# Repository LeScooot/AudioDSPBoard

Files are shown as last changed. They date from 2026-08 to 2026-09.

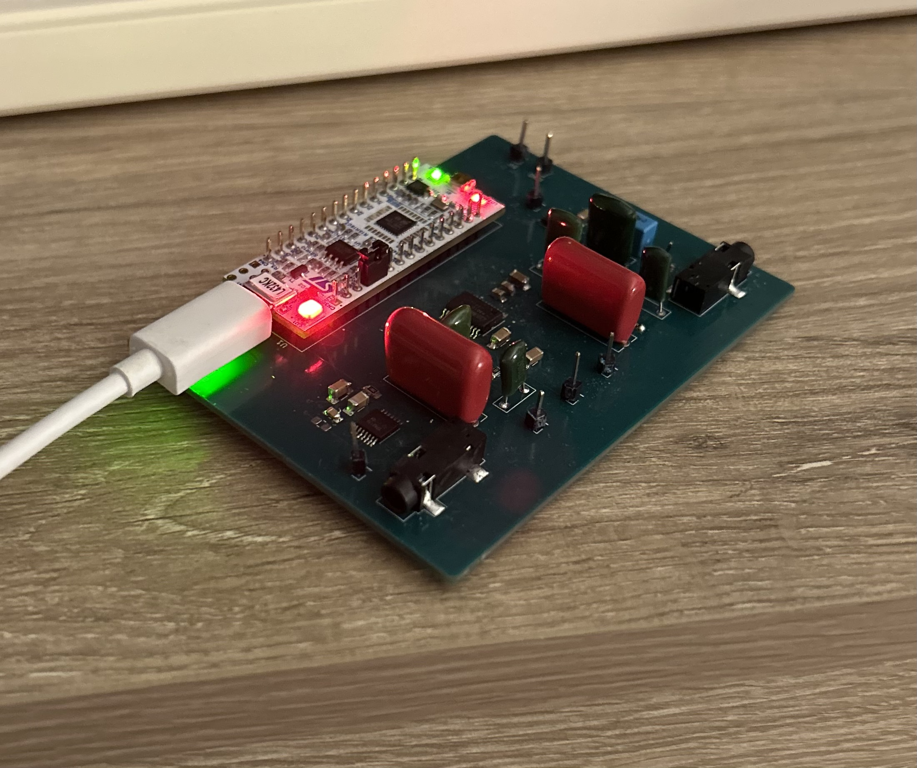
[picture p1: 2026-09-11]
hero.png

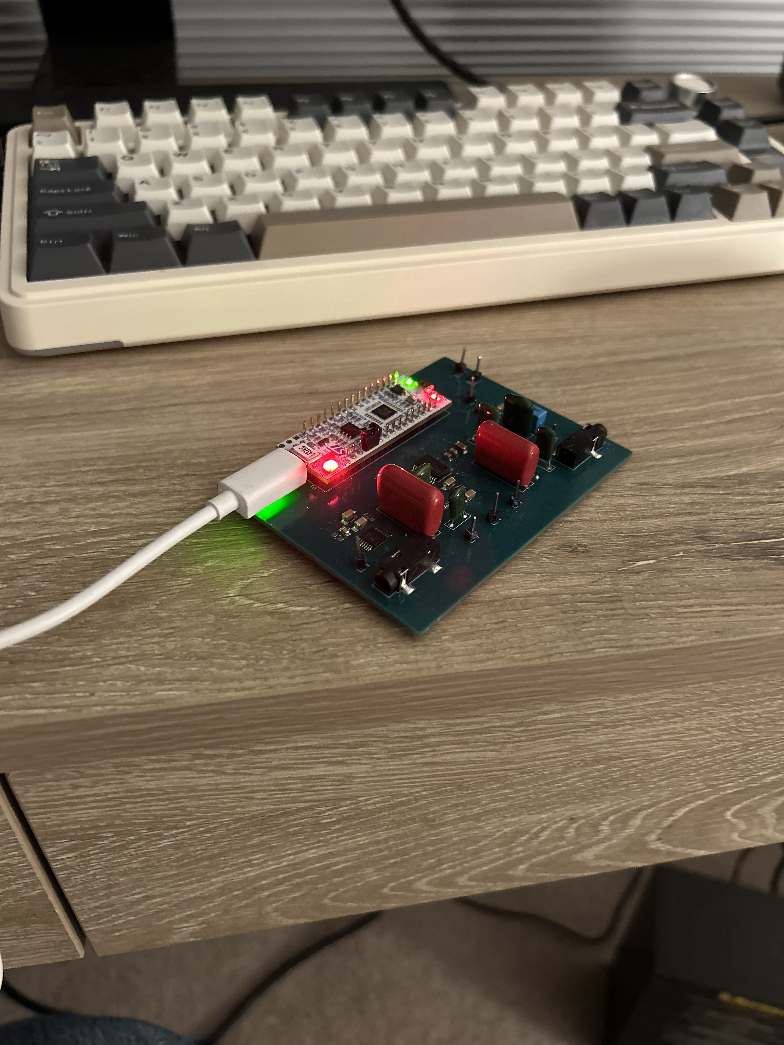
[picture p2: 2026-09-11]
audio_codec_v0/hero.png

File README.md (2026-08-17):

## Members
Ryan Jeronimus, EE Student (Graduating 2027)

ryanjeronimus@vt.edu

## Mentor
MENTOR NAME HERE

## Current Status
IN PROGRESS

## Project Overview

PCB featuring 3.5mm audio inputs and outputs, an audio CODEC for high-quality audio sampling and reconstruction, bare-metal STM32 board for implementing DSP algorithms, and a small i2c LED display for displaying information pertaining to the audio effects implemented on the STM32 (real-time display). Features programmable potentiometers and buttons for use in DSP implementations. Battery powered for ease of use when travelling. The system is intended as a portable, real-time audio effects processor for general listening applications.

## Educational Value Added
This project teaches about PCB design, power electronics, bare-metal C programming practices, and DSP for audio applications (which includes topics widely applicable to general DSP). Audio-specific communication protocols such as i2s would also be taught with the completion of this project.
## Tasks

<!-- Your Text Here. You may work with your mentor on this later when they are assigned -->

## Design Decisions

<!-- Your Text Here. You may work with your mentor on this later when they are assigned -->

## Design Misc

<!-- Your Text Here. You may work with your mentor on this later when they are assigned -->

## Steps for Documenting Your Design Process

<!-- Your Text Here. You may work with your mentor on this later when they are assigned -->

## BOM + Component Cost

<!-- Your Text Here. You may work with your mentor on this later when they are assigned -->

## Timeline

<!-- Your Text Here. You may work with your mentor on this later when they are assigned -->

## Useful Links

<!-- Your Text Here. You may work with your mentor on this later when they are assigned -->

## Log

<!-- Your Text Here. You may work with your mentor on this later when they are assigned -->

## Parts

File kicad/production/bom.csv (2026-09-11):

Designator | Footprint | Quantity | Value | LCSC Part #
C10, C14, C16, C6 | 1206 | 4 | 10uF | C13585
C11, C12, C20, C26 | 0805 | 4 | 100nF | C49678
C18, C19 | 1206 | 2 | 1uF | C1848
C23 | 1206 | 1 | 22uF | C12891
C4, C7 | 0805 | 2 | 10uF | C15850
D1 | 0805 | 1 | LED | C2297
R1 | 0805 | 1 | 130 | C178174
R10 | 0805 | 1 | 470k | C17709
R11 | 0805 | 1 | 10k | C17414
R14, R15, R16, R22 | 0805 | 4 | 1k | C702831
R17, R18 | 0805 | 2 | 2M2 | C17513
R20, R27 | 0805 | 2 | 22k | C702833
R21, R28 | 0805 | 2 | 6.8k | C17772
U13 | SOP65P640X120-14N | 1 | TPA6139A2PWR | C2870791
U2 | DB24 | 1 | PCM3010DB | C2873586
U3, U4, U5, U6 | SOT-23-5 | 4 | TLV9061xDBV | C398358

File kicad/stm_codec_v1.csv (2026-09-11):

Reference | Qty | Value | DNP | Exclude from BOM | Exclude from Board | LCSC Part # | Footprint | Datasheet
C1,C17 | 2 | 1uF | DNP | Excluded from BOM |  |  | Capacitor_THT:C_Rect_L16.5mm_W4.9mm_P15.00mm_MKT | ~
C4,C7 | 2 | 10uF |  |  |  | C1713 | Capacitor_SMD:C_0805_2012Metric_Pad1.18x1.45mm_HandSolder | ~
C6,C10,C14,C16 | 4 | 10uF |  |  |  | C1849 | Capacitor_SMD:C_1206_3216Metric_Pad1.33x1.80mm_HandSolder | ~
C11,C12,C20,C26 | 4 | 100nF |  |  |  | C1711 | Capacitor_SMD:C_0805_2012Metric_Pad1.18x1.45mm_HandSolder | ~
C18 | 1 | 1uF |  |  |  | C1848 | Capacitor_SMD:C_1206_3216Metric_Pad1.33x1.80mm_HandSolder | ~
C19 | 1 | 1uf |  |  |  | C1848 | Capacitor_SMD:C_1206_3216Metric_Pad1.33x1.80mm_HandSolder | ~
C21 | 1 | 150p | DNP | Excluded from BOM |  |  | Capacitor_THT:C_Rect_L7.0mm_W2.5mm_P5.00mm | ~
C22 | 1 | 100n | DNP | Excluded from BOM |  |  | Capacitor_THT:C_Rect_L9.0mm_W4.0mm_P7.50mm_MKT | ~
C23 | 1 | 22uF |  |  |  | C77088 | Capacitor_SMD:C_1206_3216Metric_Pad1.33x1.80mm_HandSolder | ~
C24 | 1 | 330p | DNP | Excluded from BOM |  |  | Capacitor_THT:C_Rect_L9.0mm_W4.0mm_P7.50mm_MKT | ~
C25,C36 | 2 | 1n | DNP | Excluded from BOM |  |  | Capacitor_THT:C_Rect_L7.0mm_W2.5mm_P5.00mm | ~
C37 | 1 | 330p | DNP | Excluded from BOM |  |  | Capacitor_THT:C_Rect_L7.0mm_W2.5mm_P5.00mm | ~
D1 | 1 | LED |  |  |  | C6795833 | LED_SMD:LED_0805_2012Metric_Pad1.15x1.40mm_HandSolder | ~
J1,J4,J5,J6,J7,J8,J9,J10 | 8 | Conn_01x01_Pin | DNP | Excluded from BOM |  |  | Connector_PinHeader_2.54mm:PinHeader_1x01_P2.54mm_Vertical | ~
J2,J3 | 2 | AudioJack3 | DNP | Excluded from BOM |  |  | Connector_Audio:Jack_3.5mm_CUI_SJ-3523-SMT_Horizontal | ~
R1 | 1 | 130 |  |  |  | C178174 | Resistor_SMD:R_0805_2012Metric_Pad1.20x1.40mm_HandSolder | ~
R10 | 1 | 470k |  |  |  | C49330265 | Resistor_SMD:R_0805_2012Metric_Pad1.20x1.40mm_HandSolder | ~
R11 | 1 | 10k |  |  |  | C702829 | Resistor_SMD:R_0805_2012Metric_Pad1.20x1.40mm_HandSolder | ~
R12 | 1 | 0 | DNP | Excluded from BOM |  |  | Resistor_SMD:R_0805_2012Metric_Pad1.20x1.40mm_HandSolder | ~
R14,R15,R16,R22 | 4 | 1k |  |  |  | C702831 | Resistor_SMD:R_0805_2012Metric_Pad1.20x1.40mm_HandSolder | ~
R17,R18 | 2 | 2M2 |  |  |  | C269574 | Resistor_SMD:R_0805_2012Metric_Pad1.20x1.40mm_HandSolder | ~
R20,R27 | 2 | 22k |  |  |  | C702833 | Resistor_SMD:R_0805_2012Metric_Pad1.20x1.40mm_HandSolder | ~
R21,R28 | 2 | 6.8k |  |  |  | C178216 | Resistor_SMD:R_0805_2012Metric_Pad1.20x1.40mm_HandSolder | ~
U1 | 1 | NUCLEO-L432KC | DNP | Excluded from BOM |  |  | ryan_footprints:MODULE_NUCLEO-L432KC
U2 | 1 | PCM3010DB |  |  |  | C2873586 | ryan_footprints:DB24 | https://www.ti.com/lit/gpn/pcm3010
U3,U4,U5,U6 | 4 | TLV9061xDBV |  |  |  | C398358 | Package_TO_SOT_SMD:SOT-23-5 | https://www.ti.com/lit/ds/symlink/tlv9061.pdf
U13 | 1 | TPA6139A2PWR |  |  |  | C2870791 | ryan_footprints:SOP65P640X120-14N

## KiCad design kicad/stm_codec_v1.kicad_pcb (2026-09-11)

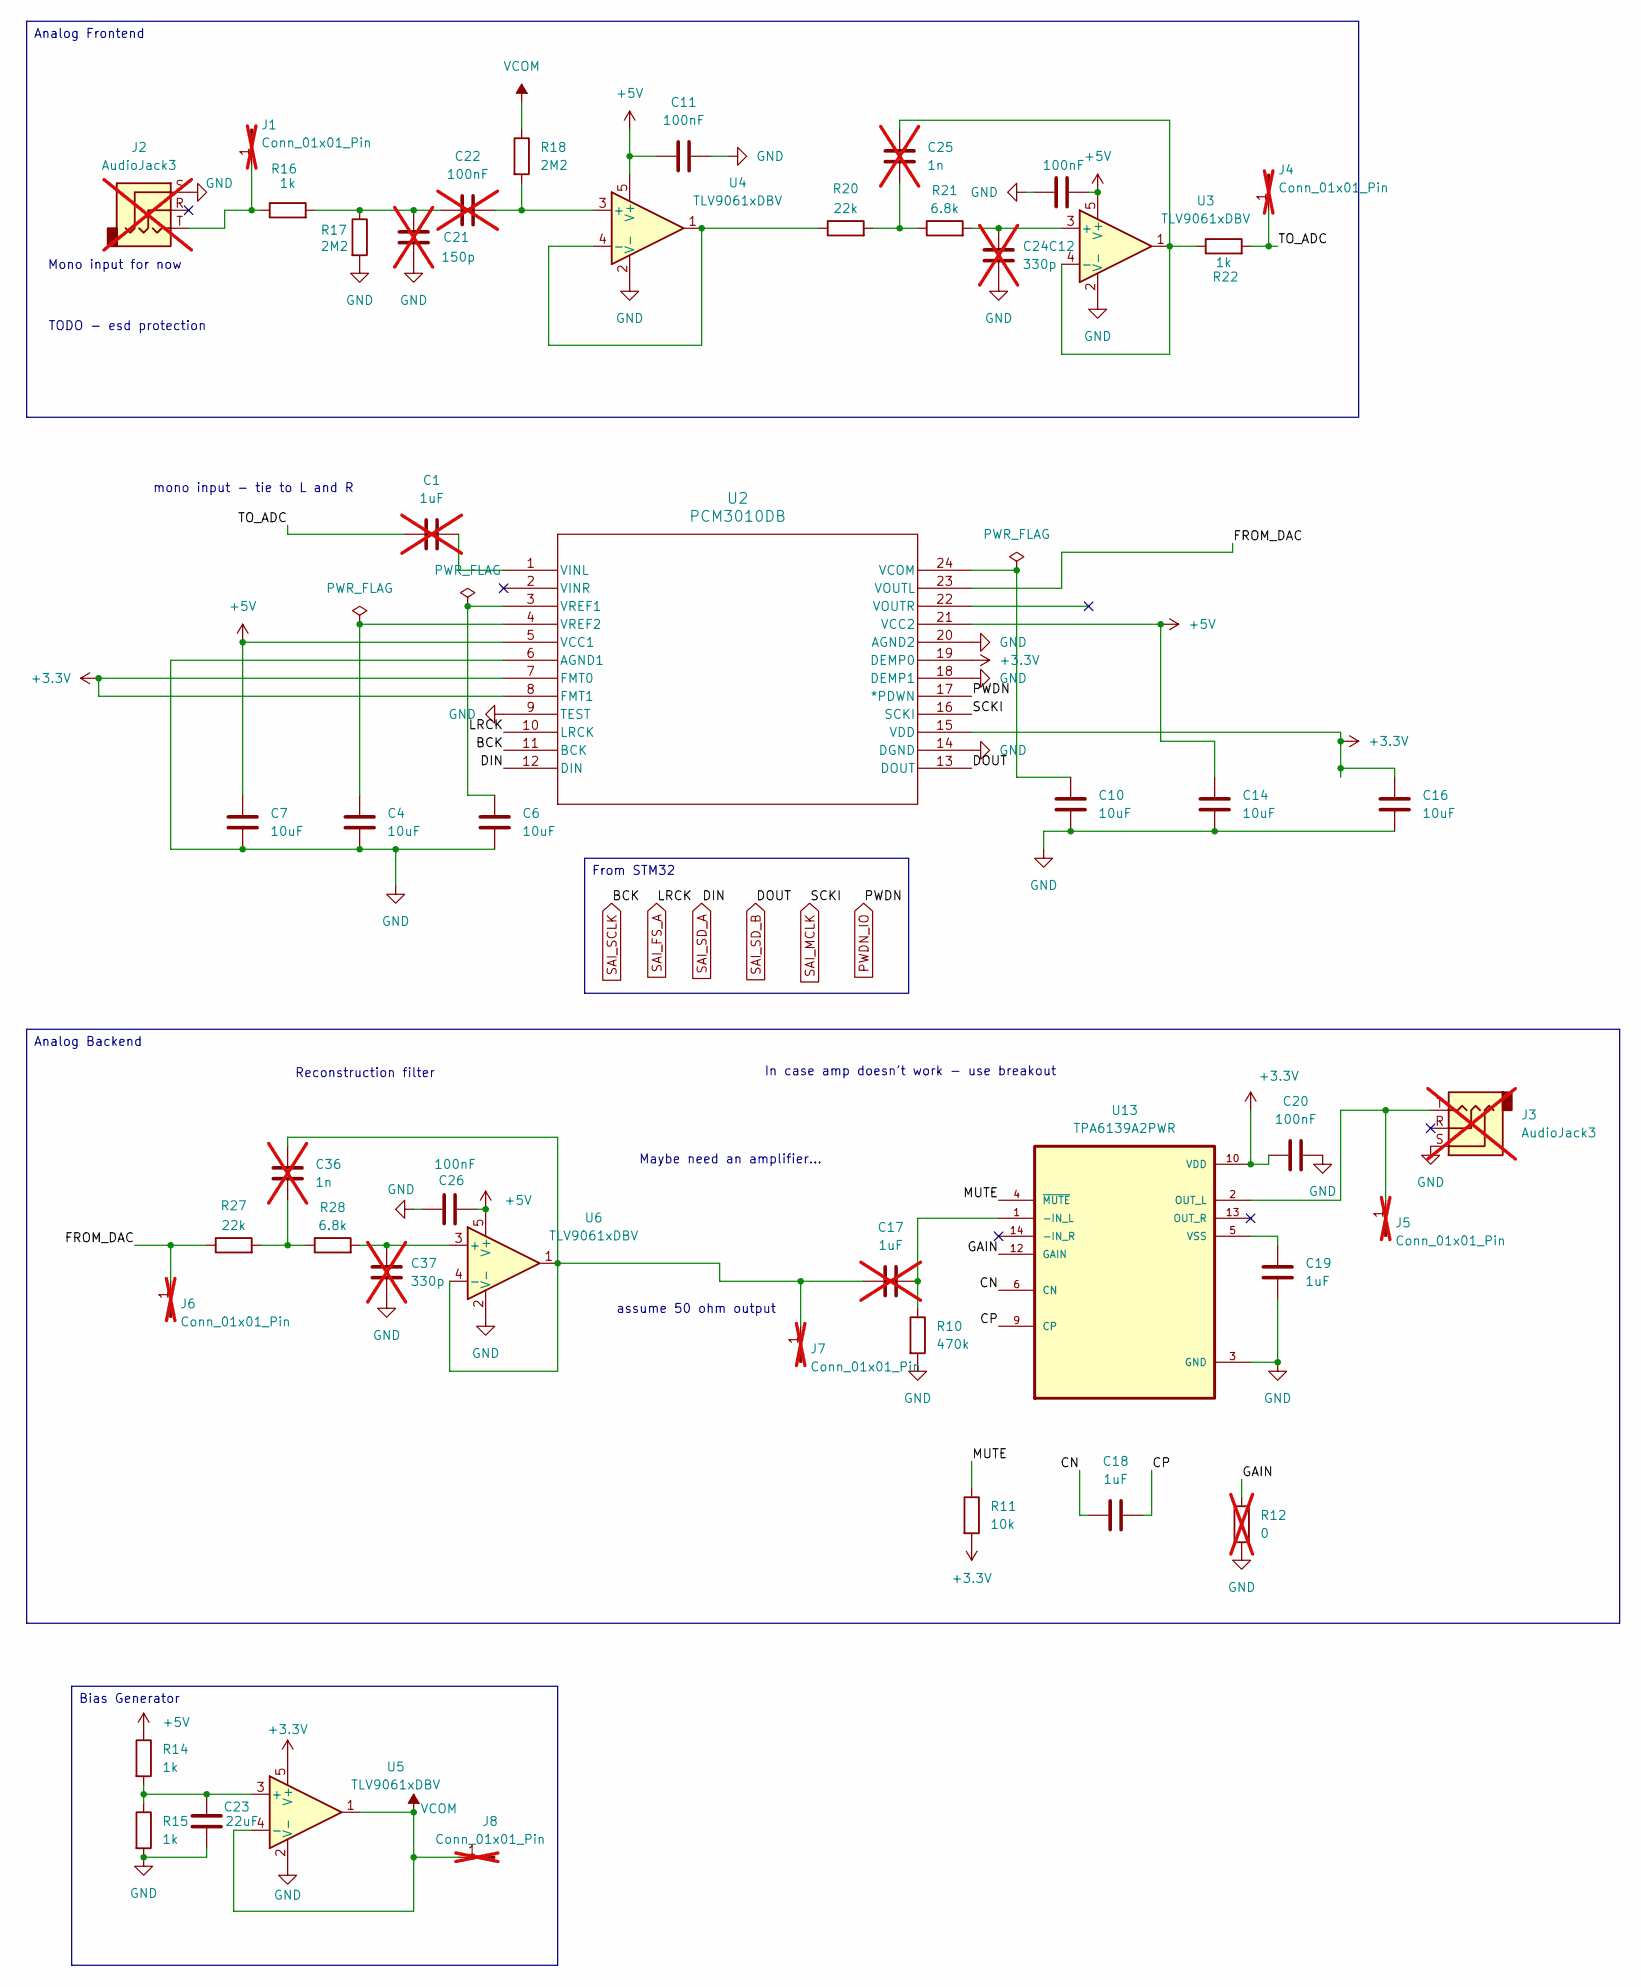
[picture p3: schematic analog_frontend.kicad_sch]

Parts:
C1, C17: 1uF; C_Rect_L16.5mm_W4.9mm_P15.00mm_MKT; not fitted
C4, C7: 10uF; C_0805_2012Metric_Pad1.18x1.45mm_HandSolder; LCSC Part # C15850
C6, C10, C14, C16: 10uF; C_1206_3216Metric_Pad1.33x1.80mm_HandSolder; LCSC Part # C13585
C11, C12, C20, C26: 100nF; C_0805_2012Metric_Pad1.18x1.45mm_HandSolder; LCSC Part # C49678
C18, C19: 1uF; C_1206_3216Metric_Pad1.33x1.80mm_HandSolder; LCSC Part # C1848
C21: 150p; C_Rect_L7.0mm_W2.5mm_P5.00mm; not fitted
C22: 100nF; C_Rect_L9.0mm_W4.0mm_P7.50mm_MKT; not fitted
C23: 22uF; C_1206_3216Metric_Pad1.33x1.80mm_HandSolder; LCSC Part # C12891
C24: 330p; C_Rect_L9.0mm_W4.0mm_P7.50mm_MKT; not fitted
C25, C36: 1n; C_Rect_L7.0mm_W2.5mm_P5.00mm; not fitted
C37: 330p; C_Rect_L7.0mm_W2.5mm_P5.00mm; not fitted
J1, J4, J5, J6, J7, J8: Conn_01x01_Pin; PinHeader_1x01_P2.54mm_Vertical; not fitted
J2, J3: AudioJack3; Jack_3.5mm_CUI_SJ-3523-SMT_Horizontal; not fitted
R10: 470k; R_0805_2012Metric_Pad1.20x1.40mm_HandSolder; LCSC Part # C17709
R11: 10k; R_0805_2012Metric_Pad1.20x1.40mm_HandSolder; LCSC Part # C17414
R12: 0; R_0805_2012Metric_Pad1.20x1.40mm_HandSolder; not fitted
R14, R15, R16, R22: 1k; R_0805_2012Metric_Pad1.20x1.40mm_HandSolder; LCSC Part # C702831
R17, R18: 2M2; R_0805_2012Metric_Pad1.20x1.40mm_HandSolder; LCSC Part # C17513
R20, R27: 22k; R_0805_2012Metric_Pad1.20x1.40mm_HandSolder; LCSC Part # C702833
R21, R28: 6.8k; R_0805_2012Metric_Pad1.20x1.40mm_HandSolder; LCSC Part # C17772
U2: PCM3010DB; DB24; LCSC Part # C2873586
U3, U4, U5, U6: TLV9061xDBV; SOT-23-5; LCSC Part # C398358
U13: TPA6139A2PWR; SOP65P640X120-14N; LCSC Part # C2870791

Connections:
+3.3V: C16.1, C20.1, R11.2, U2.7 (FMT0), U2.8 (FMT1), U2.15 (VDD), U2.19 (DEMP0), U5.5 (V+), U13.10 (VDD); also elsewhere on the board
+5V: C7.1, C11.1, C12.1, C14.1, C26.1, R14.1, U2.5 (VCC1), U2.21 (VCC2), U3.5 (V+), U4.5 (V+), U6.5 (V+); also elsewhere on the board
/Analog Frontend/CN: C18.1, U13.6 (CN)
/Analog Frontend/CP: C18.2, U13.9 (CP)
/Analog Frontend/FROM_DAC: J6.1, R27.1, U2.23 (VOUTL)
/Analog Frontend/GAIN: R12.1, U13.12 (GAIN)
/Analog Frontend/MUTE: R11.1, U13.4 (~MUTE)
/Analog Frontend/TO_ADC: C1.2, J4.1, R22.2
GND: C4.2, C6.2, C7.2, C10.2, C11.2, C12.2, C14.2, C16.2, C19.2, C20.2, C21.2, C23.2, C24.2, C26.2, C37.2, J2.S, J3.S, R10.2, R12.2, R15.2, R17.2, U2.6 (AGND1), U2.9 (TEST), U2.14 (DGND), U2.18 (DEMP1), U2.20 (AGND2), U3.2 (V-), U4.2 (V-), U5.2 (V-), U6.2 (V-), U13.3 (GND), U13.11 (GND); also elsewhere on the board
unnamed: C21.1, C22.2, R16.2, R17.1
unnamed: C25.2, R20.2, R21.1
unnamed: C36.2, R27.2, R28.1
unnamed: J1.1, J2.T, R16.1
unnamed: J3.T, J5.1, U13.2 (OUT_L)
unnamed: C17.1, C36.1, J7.1, U6.1, U6.4 (-)
unnamed: C10.1, U2.24 (VCOM)
unnamed: C1.1, U2.1 (VINL)
unnamed: C6.1, U2.3 (VREF1)
unnamed: C4.1, U2.4 (VREF2)
unnamed: C24.1, R21.2, U3.3 (+)
unnamed: C25.1, R22.1, U3.1, U3.4 (-)
unnamed: C22.1, R18.2, U4.3 (+)
unnamed: R20.1, U4.1, U4.4 (-)
unnamed: C23.1, R14.2, R15.1, U5.3 (+)
unnamed: C37.1, R28.2, U6.3 (+)
unnamed: C17.2, R10.1, U13.1 (-IN_L)
unnamed: C19.1, U13.5 (VSS)
PWDN_IO: U2.17 (*PDWN); also elsewhere on the board
SAI_FS_A: U2.10 (LRCK); also elsewhere on the board
SAI_MCLK: U2.16 (SCKI); also elsewhere on the board
SAI_SCLK: U2.11 (BCK); also elsewhere on the board
SAI_SD_A: U2.12 (DIN); also elsewhere on the board
SAI_SD_B: U2.13 (DOUT); also elsewhere on the board
VCOM: J8.1, R18.1, U5.1, U5.4 (-)

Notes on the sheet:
In case amp doesn't work - use breakout
assume 50 ohm output
Reconstruction filter
Maybe need an amplifier...
Mono input for now
mono input - tie to L and R
TODO - esd protection
Analog Frontend
Bias Generator
Analog Backend
From STM32

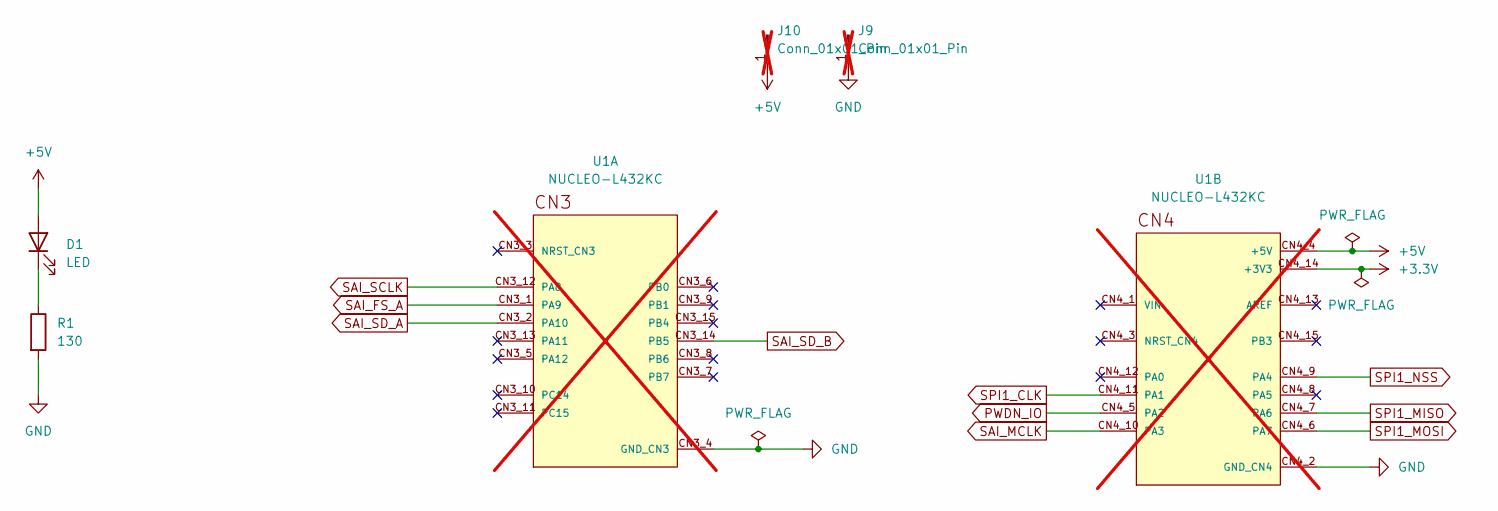
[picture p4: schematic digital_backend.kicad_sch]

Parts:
D1: LED; LED_0805_2012Metric_Pad1.15x1.40mm_HandSolder; LCSC Part # C2297
J9, J10: Conn_01x01_Pin; PinHeader_1x01_P2.54mm_Vertical; not fitted
R1: 130; R_0805_2012Metric_Pad1.20x1.40mm_HandSolder; LCSC Part # C178174
U1: NUCLEO-L432KC; MODULE_NUCLEO-L432KC; PARTREV N/A; not fitted

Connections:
+3.3V: U1.CN4_14 (+3V3); also elsewhere on the board
+5V: D1.2 (A), J10.1, U1.CN4_4 (+5V); also elsewhere on the board
GND: J9.1, R1.2, U1.CN3_4 (GND_CN3), U1.CN4_2 (GND_CN4); also elsewhere on the board
unnamed: D1.1 (K), R1.1
PWDN_IO: U1.CN4_5 (PA2); also elsewhere on the board
SAI_FS_A: U1.CN3_1 (PA9); also elsewhere on the board
SAI_MCLK: U1.CN4_10 (PA3); also elsewhere on the board
SAI_SCLK: U1.CN3_12 (PA8); also elsewhere on the board
SAI_SD_A: U1.CN3_2 (PA10); also elsewhere on the board
SAI_SD_B: U1.CN3_14 (PB5); also elsewhere on the board
SPI1_CLK: U1.CN4_11 (PA1)
SPI1_MISO: U1.CN4_7 (PA6)
SPI1_MOSI: U1.CN4_6 (PA7)
SPI1_NSS: U1.CN4_9 (PA4)

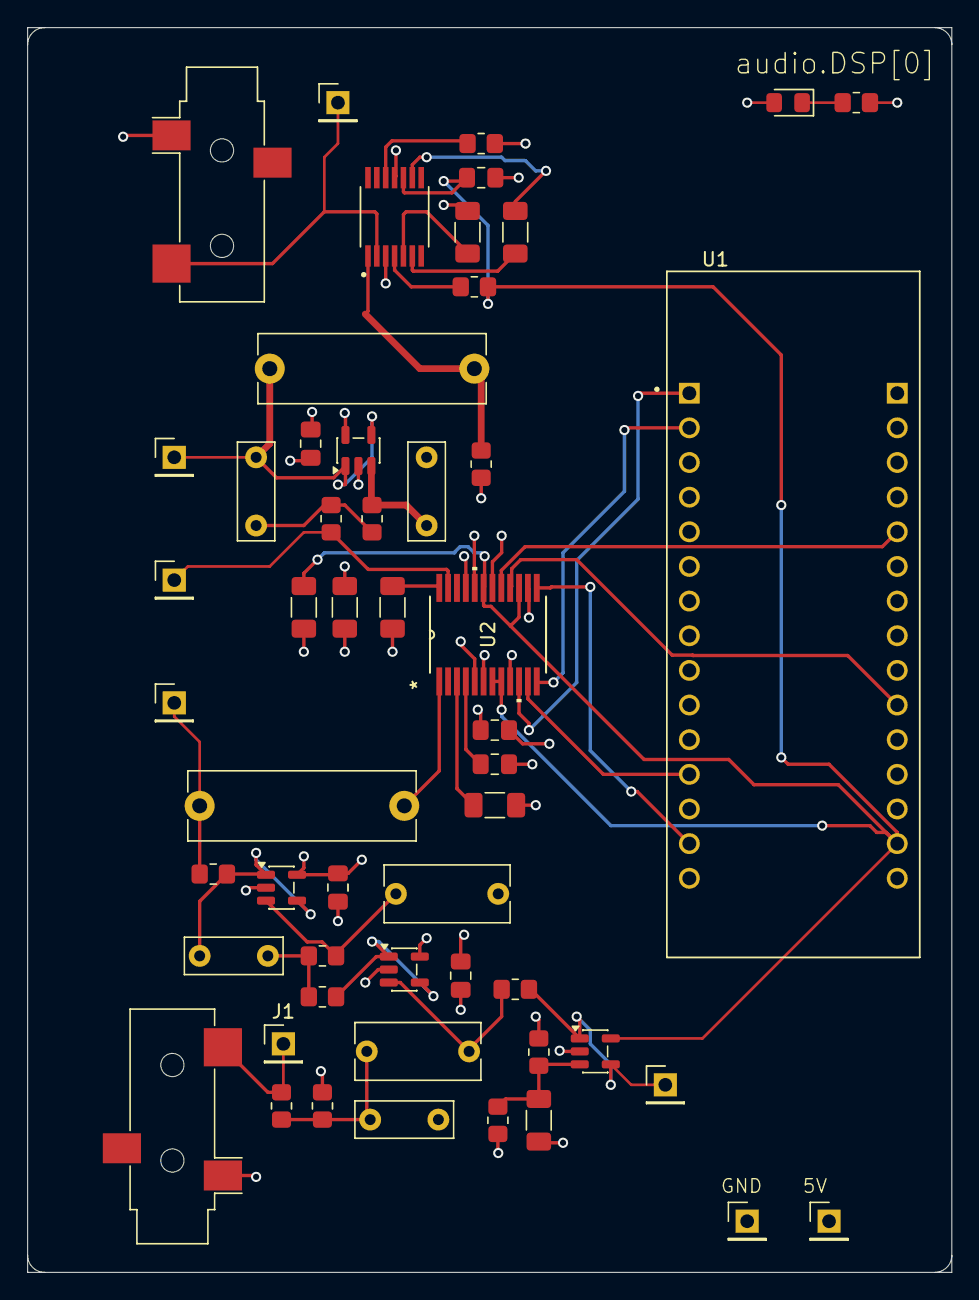
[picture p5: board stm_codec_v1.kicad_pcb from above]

Board: 4 copper layers, 67.8 x 91.2 mm, 53 parts (0 on the bottom side), 35 nets.

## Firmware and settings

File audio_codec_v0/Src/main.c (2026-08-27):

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
/* Includes ------------------------------------------------------------------*/
#include "main.h"

/* USER CODE BEGIN PD */
#define PDWN_PORT GPIOB
#define PDWN_PIN GPIO_PIN_6

/* USER CODE END PD */

SAI_HandleTypeDef hsai_BlockA1;
SAI_HandleTypeDef hsai_BlockB1;
DMA_HandleTypeDef hdma_sai1_a;
DMA_HandleTypeDef hdma_sai1_b;

UART_HandleTypeDef huart2;

void SystemClock_Config(void);
void PeriphCommonClock_Config(void);
static void MX_GPIO_Init(void);
static void MX_DMA_Init(void);
static void MX_SAI1_Init(void);
static void MX_USART2_UART_Init(void);
/**
 * @brief  The application entry point.
 * @retval int
 */
int main(void) {

	/* USER CODE BEGIN 1 */

//	HAL_Delay(2000);
	/* USER CODE END 1 */

	/* MCU Configuration--------------------------------------------------------*/

	/* Reset of all peripherals, Initializes the Flash interface and the Systick. */
	HAL_Init();

	/* Configure the system clock */
	SystemClock_Config();

	/* Configure the peripherals common clocks */
	PeriphCommonClock_Config();

	/* USER CODE BEGIN SysInit */
	printf("begin init\r\n");
	pcm3010_config.pdwn_pin = PDWN_PIN;
	pcm3010_config.pwd_port = PDWN_PORT;
	pcm3010_config.transmit_hsai = &hsai_BlockA1;
	pcm3010_config.receive_hsai = &hsai_BlockB1;

	/* USER CODE END SysInit */

	/* Initialize all configured peripherals */
	MX_GPIO_Init();
	MX_DMA_Init();
	MX_SAI1_Init();
	MX_USART2_UART_Init();
	/* USER CODE BEGIN 2 */

	init_pcm3010();
	printf("starting while loop\r\n");

	/* USER CODE END 2 */

	/* Infinite loop */
	/* USER CODE BEGIN WHILE */
	while (1) {

		if (output_ready && input_ready) {
			unity_gain(pcm3010_buffers.output_p, pcm3010_buffers.input_p, BUFFER_SIZE / 2);
			output_ready = 0;
			input_ready = 0;
		}

		/* USER CODE END WHILE */

		/* USER CODE BEGIN 3 */
	}
	/* USER CODE END 3 */
}

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
/* USER CODE BEGIN 4 */

int __io_putchar(int ch) {
	HAL_UART_Transmit(&huart2, (uint8_t*) &ch, 1, 0xFFFF);
	return ch;
}

/* USER CODE END 4 */
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


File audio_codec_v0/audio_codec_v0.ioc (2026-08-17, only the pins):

Mcu.UserName=STM32L432KCUx
PA0.GPIO_Label=MCO [High speed clock in]
PA0.Signal=RCC_CK_IN
PA10.Signal=SAI1_SD_A
PA2.GPIO_Label=VCP_TX
PA2.Signal=USART2_TX
PA3.Signal=SAI1_MCLK_A
PA8.Signal=SAI1_SCK_A
PA9.Signal=SAI1_FS_A
PB5.Signal=SAI1_SD_B
PB6.Signal=GPIO_Output

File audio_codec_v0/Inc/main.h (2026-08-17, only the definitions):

#define MCO_Pin GPIO_PIN_0
#define MCO_GPIO_Port GPIOA
#define VCP_TX_Pin GPIO_PIN_2
#define VCP_TX_GPIO_Port GPIOA
#define SWCLK_Pin GPIO_PIN_14
#define SWCLK_GPIO_Port GPIOA
#define VCP_RX_Pin GPIO_PIN_15
#define VCP_RX_GPIO_Port GPIOA
#define LD3_Pin GPIO_PIN_3
#define LD3_GPIO_Port GPIOB

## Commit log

2026-02-18 schematic finished
    [adc.kicad_sch, dac.kicad_sch, mcu.kicad_sch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]
2026-08-17 new board - unity gain firmware
2026-08-17 remove old board
    [adc.kicad_sch, dac.kicad_sch, mcu.kicad_sch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]
2026-09-11 adding design files
    [analog_frontend.kicad_sch, bom.csv, designators.csv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]

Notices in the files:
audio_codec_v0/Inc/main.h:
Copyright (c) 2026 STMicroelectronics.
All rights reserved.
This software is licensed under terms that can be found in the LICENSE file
